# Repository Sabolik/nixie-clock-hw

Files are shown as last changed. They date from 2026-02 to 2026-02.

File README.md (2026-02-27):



PCB render

# HW

- ESP32-C3 MCU
- DC/DC, non-isolated PWM power converter
- USB-C 5V power input

- up to 6 nixie tubes

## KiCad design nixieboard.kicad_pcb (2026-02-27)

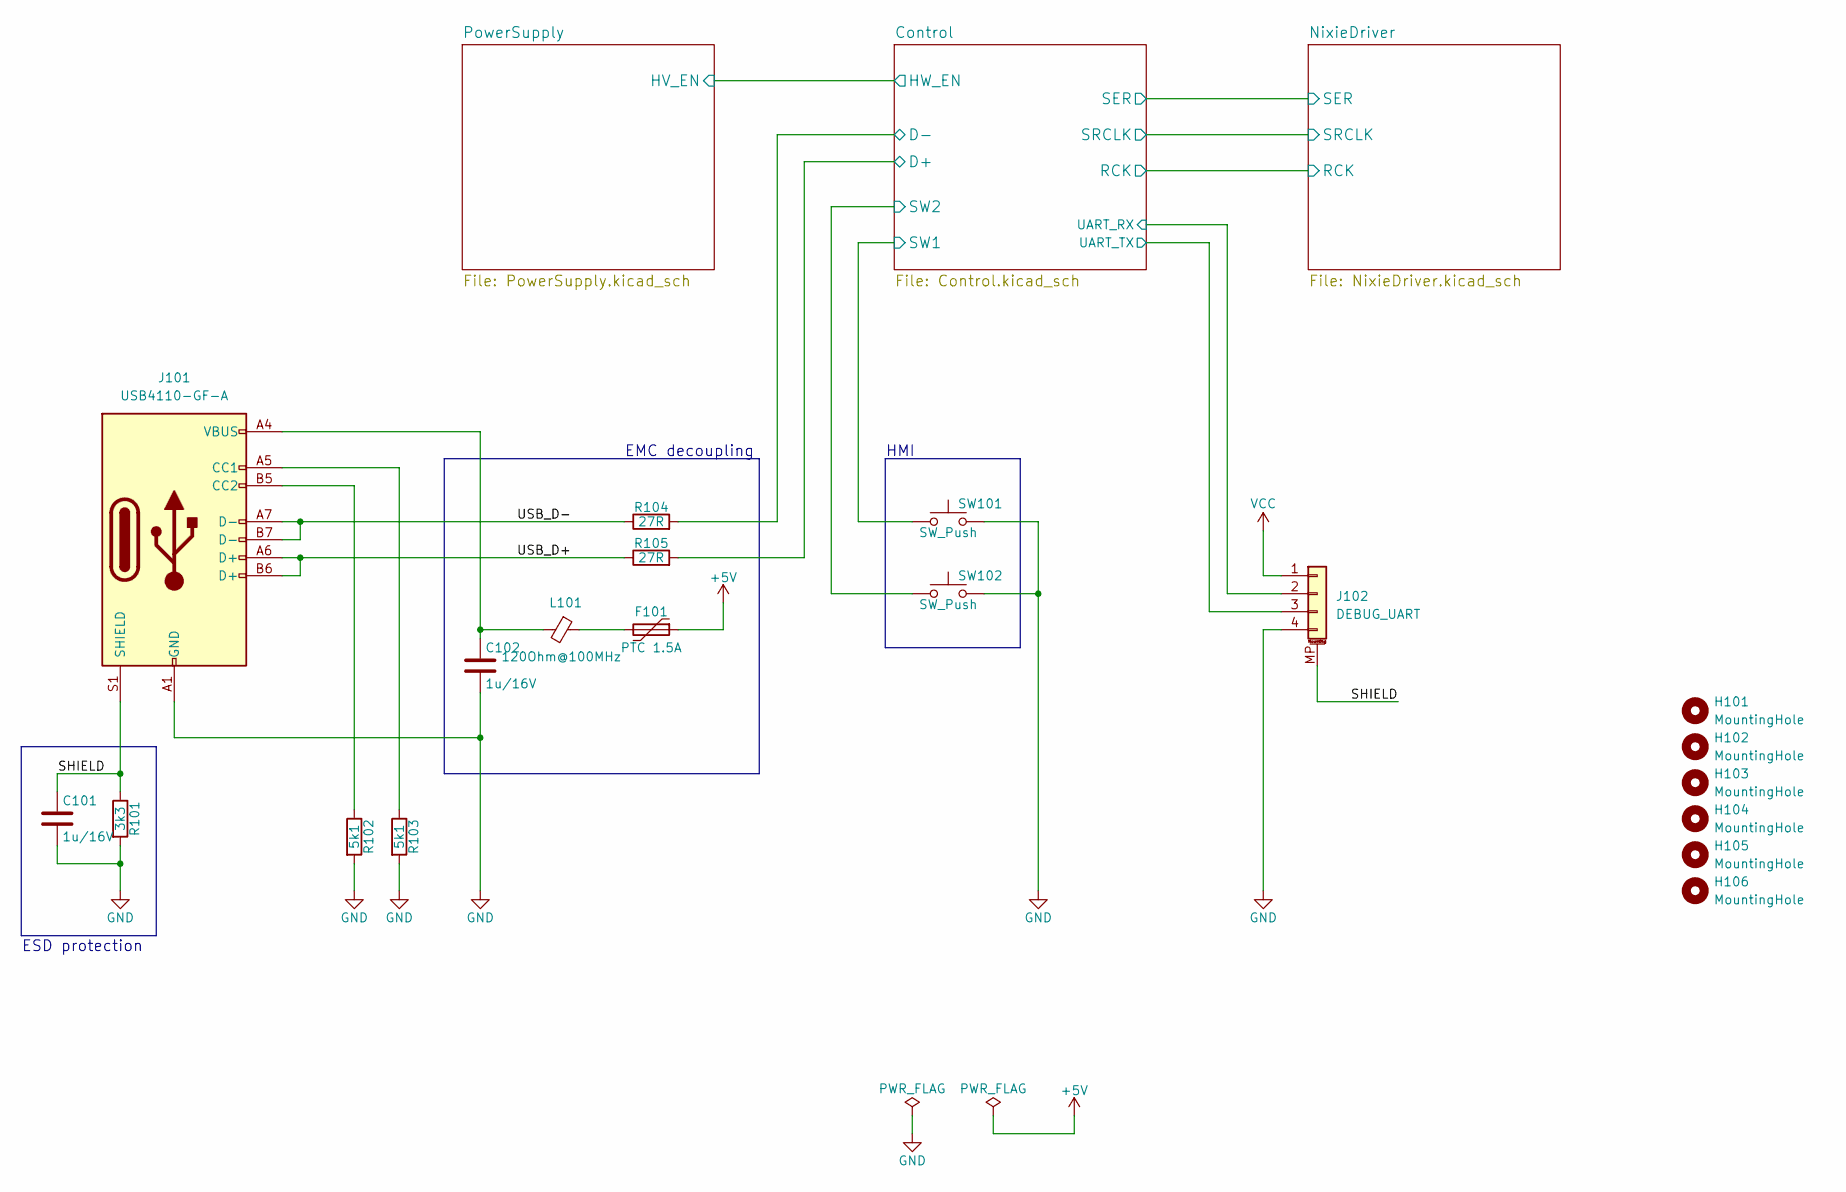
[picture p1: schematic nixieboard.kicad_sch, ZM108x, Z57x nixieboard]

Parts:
C101, C102: 1u/16V; C_0805_2012Metric
F101: PTC 1.5A; R_1812_4532Metric
H101, H102, H103, H104, H105, H106: MountingHole; MountingHole_3.2mm_M3
J101: USB4110-GF-A; USB_C_Receptacle_GCT_USB4110
J102: DEBUG_UART; Molex_PicoBlade_53261-0471_1x04-1MP_P1.25mm_Horizontal
L101: 120Ohm@100MHz; L_0805_2012Metric
R101: 3k3; R_0805_2012Metric
R102, R103: 5k1; R_0805_2012Metric
R104, R105: 27R; R_0805_2012Metric
SW101, SW102: SW_Push; SW_SPST_PTS645

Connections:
+5V: F101.1; also elsewhere on the board
/Control/D+: R105.2; also elsewhere on the board
/Control/D-: R104.2; also elsewhere on the board
/Control/SW1: SW101.1; also elsewhere on the board
/Control/SW2: SW102.1; also elsewhere on the board
/Control/UART_RX: J102.2; also elsewhere on the board
/Control/UART_TX: J102.3; also elsewhere on the board
/SHIELD: C101.1, J101.S1 (SHIELD), J102.MP (MountPin), R101.1
/USB_D+: J101.A6 (D+), J101.B6 (D+), R105.1
/USB_D-: J101.A7 (D-), J101.B7 (D-), R104.1
GND: C101.2, C102.2, J101.A1 (GND), J101.A12 (GND), J101.B1 (GND), J101.B12 (GND), J102.4, R101.2, R102.2, R103.2, SW101.2, SW102.2; also elsewhere on the board
unnamed: C102.1, J101.A4 (VBUS), J101.A9 (VBUS), J101.B4 (VBUS), J101.B9 (VBUS), L101.2
unnamed: F101.2, L101.1
unnamed: J101.A5 (CC1), R103.1
unnamed: J101.B5 (CC2), R102.1
VCC: J102.1; also elsewhere on the board

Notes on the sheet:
EMC decoupling
ESD protection
HMI

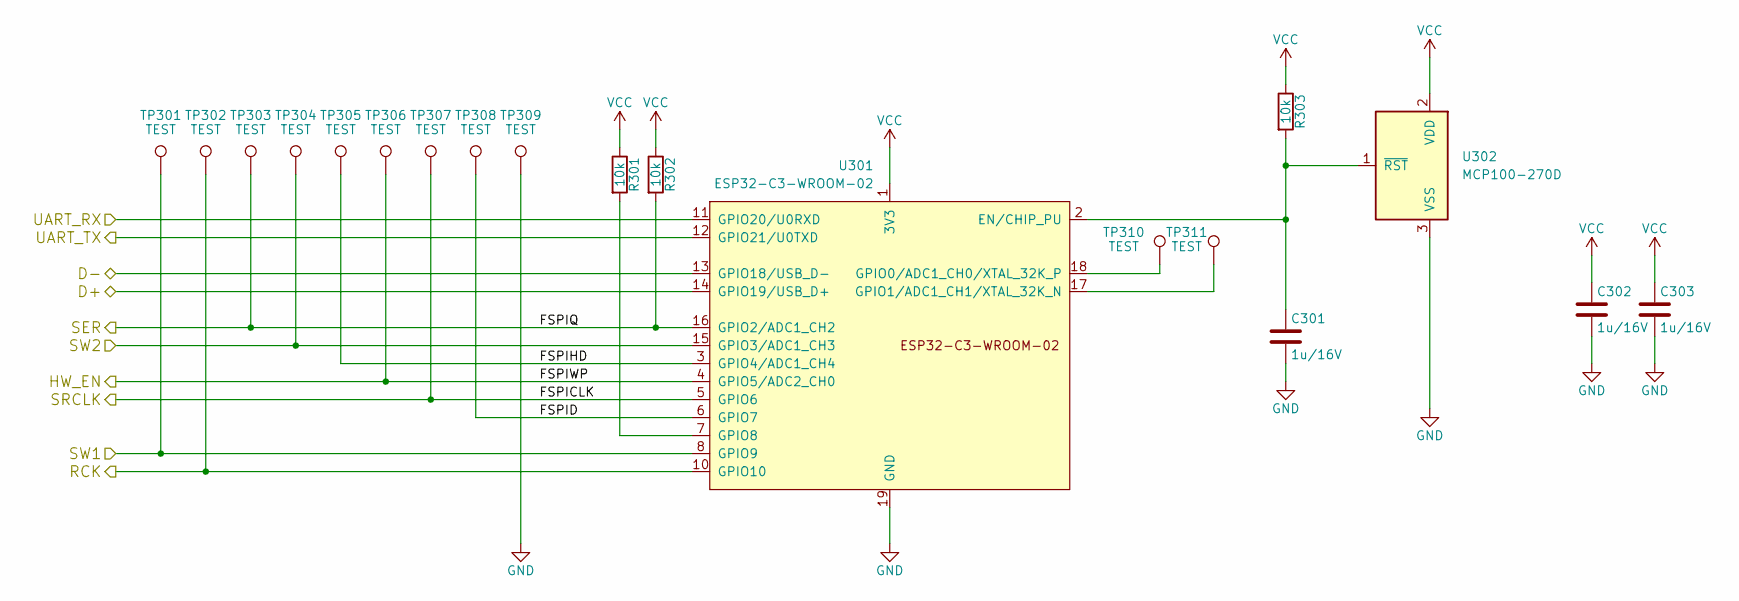
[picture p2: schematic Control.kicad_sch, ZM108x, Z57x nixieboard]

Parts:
C301, C302, C303: 1u/16V; C_0805_2012Metric
R301, R302, R303: 10k; R_0805_2012Metric
TP301, TP302, TP303, TP304, TP305, TP306, TP307, TP308, TP309, TP310, TP311: TEST; TestPoint_Pad_D1.5mm
U301: ESP32-C3-WROOM-02
U302: MCP100-270D; SOT-23-3

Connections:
/Control/D+: U301.14 (GPIO19/USB_D+); also elsewhere on the board
/Control/D-: U301.13 (GPIO18/USB_D-); also elsewhere on the board
/Control/FSPICLK: TP307.1, U301.5 (GPIO6); also elsewhere on the board
/Control/FSPID: TP308.1, U301.6 (GPIO7)
/Control/FSPIHD: TP305.1, U301.3 (GPIO4/ADC1_CH4)
/Control/FSPIQ: R302.2, TP303.1, U301.16 (GPIO2/ADC1_CH2); also elsewhere on the board
/Control/FSPIWP: TP306.1, U301.4 (GPIO5/ADC2_CH0); also elsewhere on the board
/Control/RCK: TP302.1, U301.10 (GPIO10); also elsewhere on the board
/Control/SW1: TP301.1, U301.8 (GPIO9); also elsewhere on the board
/Control/SW2: TP304.1, U301.15 (GPIO3/ADC1_CH3); also elsewhere on the board
/Control/UART_RX: U301.11 (GPIO20/U0RXD); also elsewhere on the board
/Control/UART_TX: U301.12 (GPIO21/U0TXD); also elsewhere on the board
GND: C301.2, C302.2, C303.2, TP309.1, U301.9 (GND), U301.19 (GND), U302.3 (VSS); also elsewhere on the board
unnamed: C301.1, R303.2, U301.2 (EN/CHIP_PU), U302.1 (~RST)
unnamed: TP310.1, U301.18 (GPIO0/ADC1_CH0/XTAL_32K_P)
unnamed: TP311.1, U301.17 (GPIO1/ADC1_CH1/XTAL_32K_N)
unnamed: R301.2, U301.7 (GPIO8)
VCC: C302.1, C303.1, R301.1, R302.1, R303.1, U301.1 (3V3), U302.2 (VDD); also elsewhere on the board

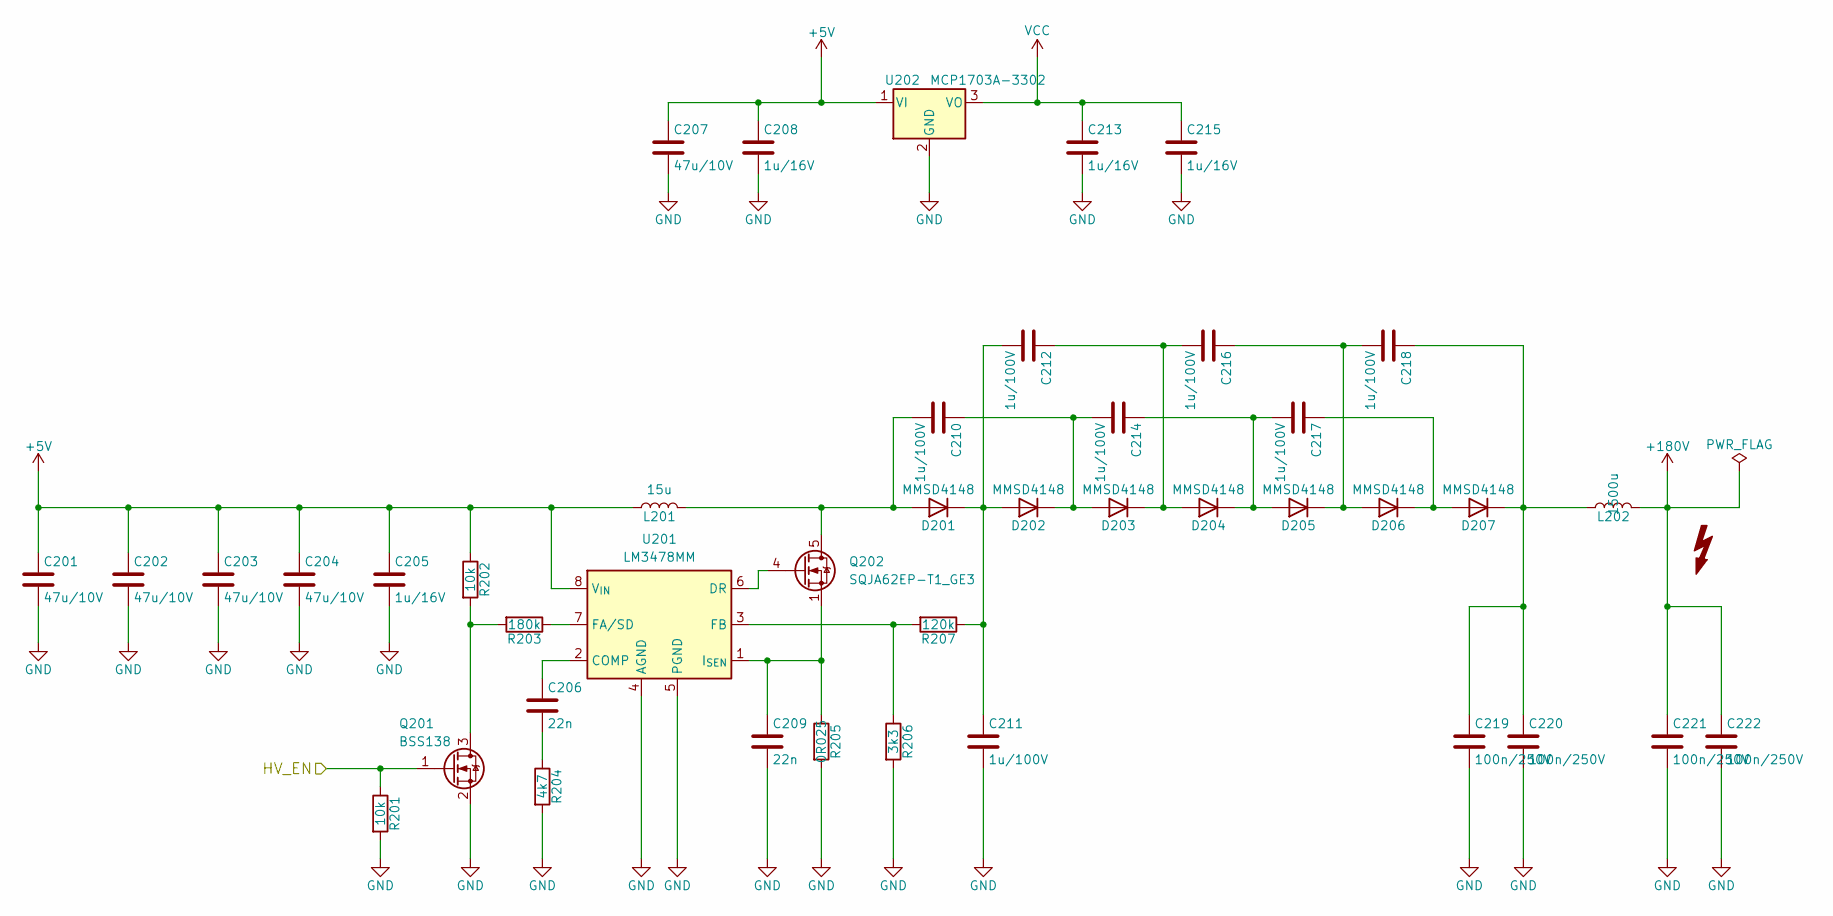
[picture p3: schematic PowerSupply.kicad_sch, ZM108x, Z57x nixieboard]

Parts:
C201, C202, C203, C204, C207: 47u/10V; C_1206_3216Metric
C205, C208, C213, C215: 1u/16V; C_0805_2012Metric
C206, C209: 22n; C_0805_2012Metric
C210, C211, C212, C214, C216, C217, C218: 1u/100V; C_1206_3216Metric
C219, C220, C221, C222: 100n/250V; C_1206_3216Metric
D201, D202, D203, D204, D205, D206, D207: MMSD4148; D_SOD-123
L201: 15u; L_Bourns_SRR1208_12.7x12.7mm
L202: 1500u; L_1812_4532Metric
Q201: BSS138; SOT-23
Q202: SQJA62EP-T1_GE3; PowerPAK_SO-8_Single
R201, R202: 10k; R_0805_2012Metric
R203: 180k; R_0805_2012Metric
R204: 4k7; R_0805_2012Metric
R205: 0R025; R_0805_2012Metric
R206: 3k3; R_0805_2012Metric
R207: 120k; R_0805_2012Metric
U201: LM3478MM; VSSOP-8_3.0x3.0mm_P0.65mm
U202: MCP1703A-3302; SOT-223-3_TabPin2

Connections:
+5V: C201.1, C202.1, C203.1, C204.1, C205.1, C207.1, C208.1, L201.1, R202.1, U201.8 (V_{IN}), U202.1 (VI); also elsewhere on the board
/Control/FSPIWP: Q201.1 (G), R201.1; also elsewhere on the board
GND: C201.2, C202.2, C203.2, C204.2, C205.2, C207.2, C208.2, C209.2, C211.2, C213.2, C215.2, C219.2, C220.2, C221.2, C222.2, Q201.2 (S), R201.2, R204.2, R205.2, R206.2, U201.4 (AGND), U201.5 (PGND), U202.2 (GND); also elsewhere on the board
unnamed: C206.2, R204.1
unnamed: C210.2, D201.2 (A), L201.2, Q202.5 (D)
unnamed: C211.1, C212.2, D201.1 (K), D202.2 (A), R207.1
unnamed: C210.1, C214.2, D202.1 (K), D203.2 (A)
unnamed: C212.1, C216.2, D203.1 (K), D204.2 (A)
unnamed: C214.1, C217.2, D204.1 (K), D205.2 (A)
unnamed: C216.1, C218.2, D205.1 (K), D206.2 (A)
unnamed: C217.1, D206.1 (K), D207.2 (A)
unnamed: C218.1, C219.1, C220.1, D207.1 (K), L202.1
unnamed: Q201.3 (D), R202.2, R203.2
unnamed: Q202.4 (G), U201.6 (DR)
unnamed: C206.1, U201.2 (COMP)
unnamed: R203.1, U201.7 (FA/SD)
unnamed: R206.1, R207.2, U201.3 (FB)
unnamed: C209.1, Q202.1 (S), Q202.2 (S), Q202.3 (S), R205.1, U201.1 (I_{SEN})
VCC: C213.1, C215.1, U202.3 (VO); also elsewhere on the board
Vdrive: C221.1, C222.1, L202.2; also elsewhere on the board

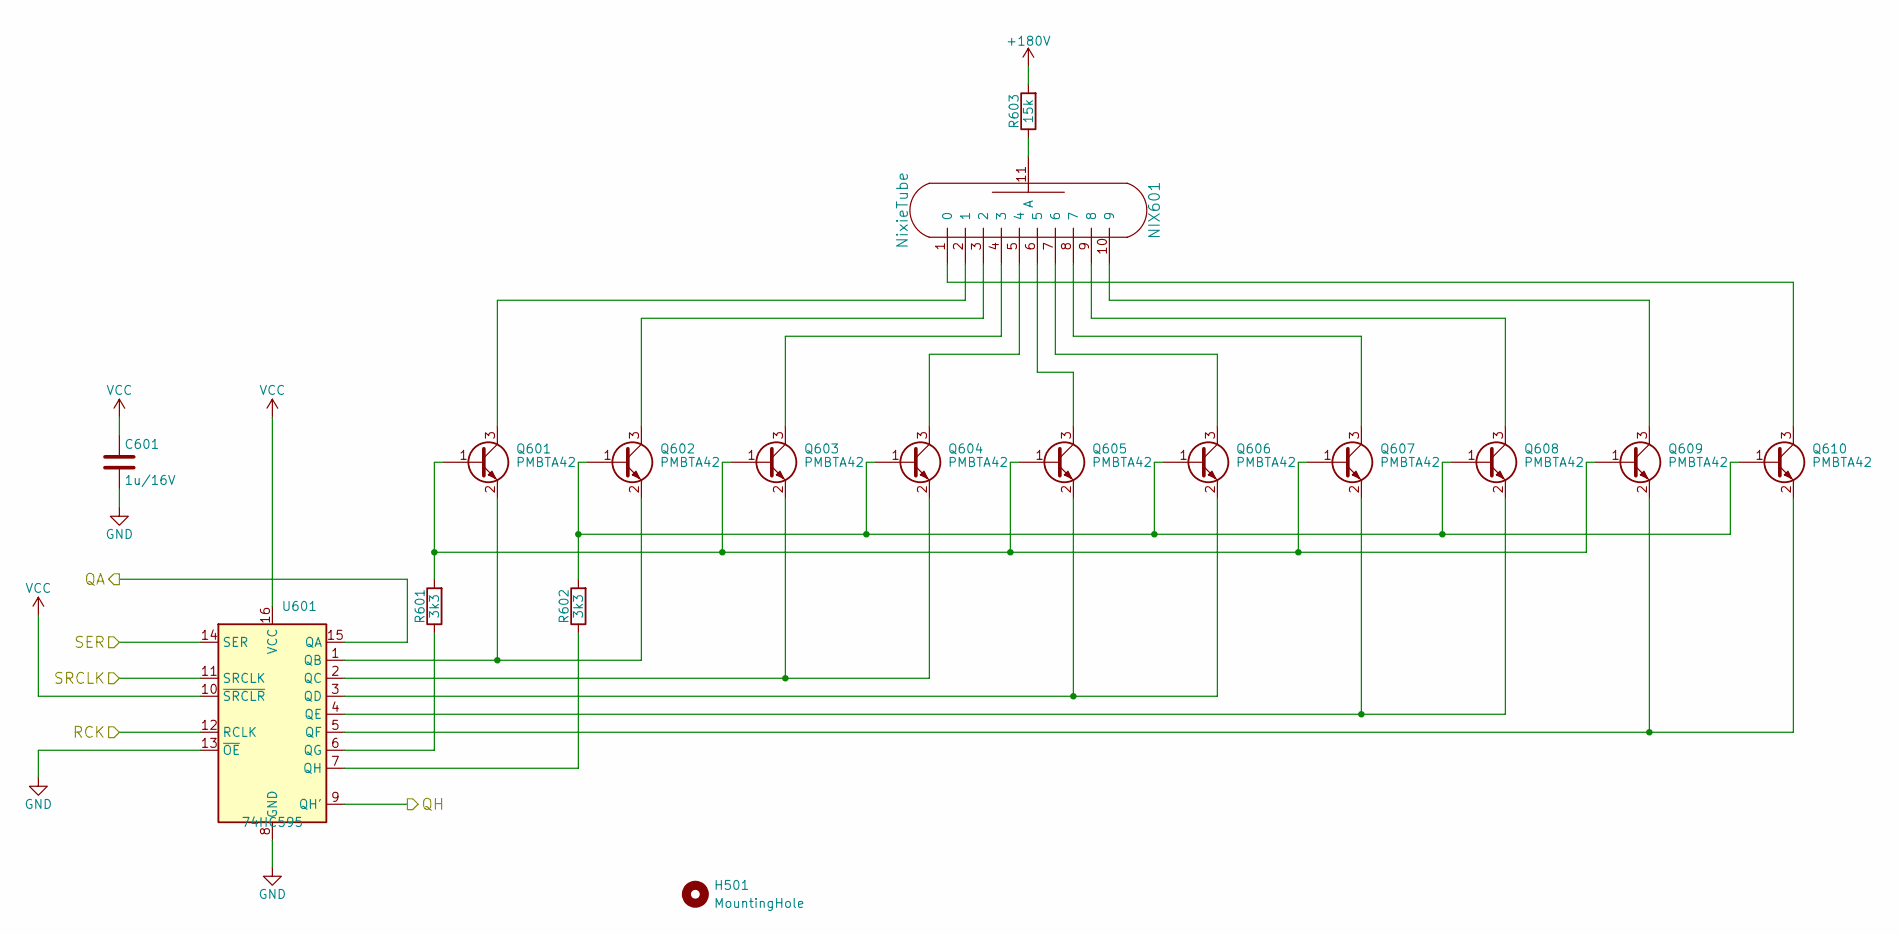
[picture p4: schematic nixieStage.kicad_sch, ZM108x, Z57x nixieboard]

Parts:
C601: 1u/16V; C_0805_2012Metric
H501: MountingHole; MountingHole_5.3mm_M5
NIX601: NixieTube; Zxxx
Q601, Q602, Q603, Q604, Q605, Q606, Q607, Q608, Q609, Q610: PMBTA42; SOT-23
R601, R602: 3k3; R_0603_1608Metric
R603: 15k; R_1206_3216Metric
U601: 74HC595; TSSOP-16_4.4x5mm_P0.65mm

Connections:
/Control/FSPICLK: U601.11 (SRCLK); also elsewhere on the board
/Control/RCK: U601.12 (RCLK); also elsewhere on the board
/NixieDriver/neon0/NEON: U601.15 (QA); also elsewhere on the board
/NixieDriver/nixieStage0/QH: U601.14 (SER); also elsewhere on the board
/NixieDriver/nixieStage1/QH: U601.9 (QH'); also elsewhere on the board
GND: C601.2, U601.8 (GND), U601.13 (~OE); also elsewhere on the board
unnamed: NIX601.1 (0), Q610.3 (C)
unnamed: NIX601.2 (1), Q601.3 (C)
unnamed: NIX601.3 (2), Q602.3 (C)
unnamed: NIX601.4 (3), Q603.3 (C)
unnamed: NIX601.5 (4), Q604.3 (C)
unnamed: NIX601.6 (5), Q605.3 (C)
unnamed: NIX601.7 (6), Q606.3 (C)
unnamed: NIX601.8 (7), Q607.3 (C)
unnamed: NIX601.9 (8), Q608.3 (C)
unnamed: NIX601.10 (9), Q609.3 (C)
unnamed: NIX601.11 (A), R603.1
unnamed: Q601.1 (B), Q603.1 (B), Q605.1 (B), Q607.1 (B), Q609.1 (B), R601.2
unnamed: Q601.2 (E), Q602.2 (E), U601.1 (QB)
unnamed: Q602.1 (B), Q604.1 (B), Q606.1 (B), Q608.1 (B), Q610.1 (B), R602.2
unnamed: Q603.2 (E), Q604.2 (E), U601.2 (QC)
unnamed: Q605.2 (E), Q606.2 (E), U601.3 (QD)
unnamed: Q607.2 (E), Q608.2 (E), U601.4 (QE)
unnamed: Q609.2 (E), Q610.2 (E), U601.5 (QF)
unnamed: R601.1, U601.6 (QG)
unnamed: R602.1, U601.7 (QH)
VCC: C601.1, U601.10 (~SRCLR), U601.16 (VCC); also elsewhere on the board
Vdrive: R603.2; also elsewhere on the board

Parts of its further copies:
C501, C701, C901, C1001, C1201: 1u/16V; C_0805_2012Metric
H601, H701, H901, H1001, H1201: MountingHole; MountingHole_5.3mm_M5
NIX501, NIX701, NIX901, NIX1001, NIX1201: NixieTube; Zxxx
Q501, Q502, Q503, Q504, Q505, Q506, Q507, Q508, Q509, Q510, Q701, Q702, Q703, Q704, Q705, Q706, Q707, Q708, Q709, Q710, Q901, Q902, Q903, Q904, Q905, Q906, Q907, Q908, Q909, Q910, Q1001, Q1002, Q1003, Q1004, Q1005, Q1006, Q1007, Q1008, Q1009, Q1010, Q1201, Q1202, Q1203, Q1204, Q1205, Q1206, Q1207, Q1208, Q1209, Q1210: PMBTA42; SOT-23
R501, R502, R701, R702, R901, R902, R1001, R1002, R1201, R1202: 3k3; R_0603_1608Metric
R503, R703, R903, R1003, R1203: 15k; R_1206_3216Metric
U501, U701, U901, U1001, U1201: 74HC595; TSSOP-16_4.4x5mm_P0.65mm

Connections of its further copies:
/Control/FSPICLK: U501.11 (SRCLK), U701.11 (SRCLK), U901.11 (SRCLK), U1001.11 (SRCLK), U1201.11 (SRCLK); also elsewhere on the board
/Control/FSPIQ: U501.14 (SER); also elsewhere on the board
/Control/RCK: U501.12 (RCLK), U701.12 (RCLK), U901.12 (RCLK), U1001.12 (RCLK), U1201.12 (RCLK); also elsewhere on the board
/NixieDriver/neon1/NEON: U901.15 (QA); also elsewhere on the board
/NixieDriver/nixieStage0/QA: U501.15 (QA)
/NixieDriver/nixieStage0/QH: U501.9 (QH'); also elsewhere on the board
/NixieDriver/nixieStage1/QH: U701.14 (SER); also elsewhere on the board
/NixieDriver/nixieStage2/QA: U701.15 (QA)
/NixieDriver/nixieStage2/QH: U701.9 (QH'), U901.14 (SER)
/NixieDriver/nixieStage3/QH: U901.9 (QH'), U1001.14 (SER)
/NixieDriver/nixieStage4/QA: U1001.15 (QA)
/NixieDriver/nixieStage4/QH: U1001.9 (QH'), U1201.14 (SER)
/NixieDriver/nixieStage5/QA: U1201.15 (QA)
/NixieDriver/nixieStage5/QH: U1201.9 (QH')
GND: C501.2, C701.2, C901.2, C1001.2, C1201.2, U501.8 (GND), U501.13 (~OE), U701.8 (GND), U701.13 (~OE), U901.8 (GND), U901.13 (~OE), U1001.8 (GND), U1001.13 (~OE), U1201.8 (GND), U1201.13 (~OE); also elsewhere on the board
unnamed: NIX501.1 (0), Q510.3 (C)
unnamed: NIX501.2 (1), Q501.3 (C)
unnamed: NIX501.3 (2), Q502.3 (C)
unnamed: NIX501.4 (3), Q503.3 (C)
unnamed: NIX501.5 (4), Q504.3 (C)
unnamed: NIX501.6 (5), Q505.3 (C)
unnamed: NIX501.7 (6), Q506.3 (C)
unnamed: NIX501.8 (7), Q507.3 (C)
unnamed: NIX501.9 (8), Q508.3 (C)
unnamed: NIX501.10 (9), Q509.3 (C)
unnamed: NIX501.11 (A), R503.1
unnamed: NIX701.1 (0), Q710.3 (C)
unnamed: NIX701.2 (1), Q701.3 (C)
unnamed: NIX701.3 (2), Q702.3 (C)
unnamed: NIX701.4 (3), Q703.3 (C)
unnamed: NIX701.5 (4), Q704.3 (C)
unnamed: NIX701.6 (5), Q705.3 (C)
unnamed: NIX701.7 (6), Q706.3 (C)
unnamed: NIX701.8 (7), Q707.3 (C)
unnamed: NIX701.9 (8), Q708.3 (C)
unnamed: NIX701.10 (9), Q709.3 (C)
unnamed: NIX701.11 (A), R703.1
unnamed: NIX901.1 (0), Q910.3 (C)
unnamed: NIX901.2 (1), Q901.3 (C)
unnamed: NIX901.3 (2), Q902.3 (C)
unnamed: NIX901.4 (3), Q903.3 (C)
unnamed: NIX901.5 (4), Q904.3 (C)
unnamed: NIX901.6 (5), Q905.3 (C)
unnamed: NIX901.7 (6), Q906.3 (C)
unnamed: NIX901.8 (7), Q907.3 (C)
unnamed: NIX901.9 (8), Q908.3 (C)
unnamed: NIX901.10 (9), Q909.3 (C)
unnamed: NIX901.11 (A), R903.1
unnamed: NIX1001.1 (0), Q1010.3 (C)
unnamed: NIX1001.2 (1), Q1001.3 (C)
unnamed: NIX1001.3 (2), Q1002.3 (C)
unnamed: NIX1001.4 (3), Q1003.3 (C)
unnamed: NIX1001.5 (4), Q1004.3 (C)
unnamed: NIX1001.6 (5), Q1005.3 (C)
unnamed: NIX1001.7 (6), Q1006.3 (C)
unnamed: NIX1001.8 (7), Q1007.3 (C)
unnamed: NIX1001.9 (8), Q1008.3 (C)
unnamed: NIX1001.10 (9), Q1009.3 (C)
unnamed: NIX1001.11 (A), R1003.1
unnamed: NIX1201.1 (0), Q1210.3 (C)
unnamed: NIX1201.2 (1), Q1201.3 (C)
unnamed: NIX1201.3 (2), Q1202.3 (C)
unnamed: NIX1201.4 (3), Q1203.3 (C)
unnamed: NIX1201.5 (4), Q1204.3 (C)
unnamed: NIX1201.6 (5), Q1205.3 (C)
unnamed: NIX1201.7 (6), Q1206.3 (C)
unnamed: NIX1201.8 (7), Q1207.3 (C)
unnamed: NIX1201.9 (8), Q1208.3 (C)
unnamed: NIX1201.10 (9), Q1209.3 (C)
unnamed: NIX1201.11 (A), R1203.1
unnamed: Q501.1 (B), Q503.1 (B), Q505.1 (B), Q507.1 (B), Q509.1 (B), R501.2
unnamed: Q501.2 (E), Q502.2 (E), U501.1 (QB)
unnamed: Q502.1 (B), Q504.1 (B), Q506.1 (B), Q508.1 (B), Q510.1 (B), R502.2
unnamed: Q503.2 (E), Q504.2 (E), U501.2 (QC)
unnamed: Q505.2 (E), Q506.2 (E), U501.3 (QD)
unnamed: Q507.2 (E), Q508.2 (E), U501.4 (QE)
unnamed: Q509.2 (E), Q510.2 (E), U501.5 (QF)
unnamed: Q701.1 (B), Q703.1 (B), Q705.1 (B), Q707.1 (B), Q709.1 (B), R701.2
unnamed: Q701.2 (E), Q702.2 (E), U701.1 (QB)
unnamed: Q702.1 (B), Q704.1 (B), Q706.1 (B), Q708.1 (B), Q710.1 (B), R702.2
unnamed: Q703.2 (E), Q704.2 (E), U701.2 (QC)
unnamed: Q705.2 (E), Q706.2 (E), U701.3 (QD)
unnamed: Q707.2 (E), Q708.2 (E), U701.4 (QE)
unnamed: Q709.2 (E), Q710.2 (E), U701.5 (QF)
unnamed: Q901.1 (B), Q903.1 (B), Q905.1 (B), Q907.1 (B), Q909.1 (B), R901.2
unnamed: Q901.2 (E), Q902.2 (E), U901.1 (QB)
unnamed: Q902.1 (B), Q904.1 (B), Q906.1 (B), Q908.1 (B), Q910.1 (B), R902.2
unnamed: Q903.2 (E), Q904.2 (E), U901.2 (QC)
unnamed: Q905.2 (E), Q906.2 (E), U901.3 (QD)
unnamed: Q907.2 (E), Q908.2 (E), U901.4 (QE)
unnamed: Q909.2 (E), Q910.2 (E), U901.5 (QF)
unnamed: Q1001.1 (B), Q1003.1 (B), Q1005.1 (B), Q1007.1 (B), Q1009.1 (B), R1001.2
unnamed: Q1001.2 (E), Q1002.2 (E), U1001.1 (QB)
unnamed: Q1002.1 (B), Q1004.1 (B), Q1006.1 (B), Q1008.1 (B), Q1010.1 (B), R1002.2
unnamed: Q1003.2 (E), Q1004.2 (E), U1001.2 (QC)
unnamed: Q1005.2 (E), Q1006.2 (E), U1001.3 (QD)
unnamed: Q1007.2 (E), Q1008.2 (E), U1001.4 (QE)
unnamed: Q1009.2 (E), Q1010.2 (E), U1001.5 (QF)
unnamed: Q1201.1 (B), Q1203.1 (B), Q1205.1 (B), Q1207.1 (B), Q1209.1 (B), R1201.2
unnamed: Q1201.2 (E), Q1202.2 (E), U1201.1 (QB)
unnamed: Q1202.1 (B), Q1204.1 (B), Q1206.1 (B), Q1208.1 (B), Q1210.1 (B), R1202.2
unnamed: Q1203.2 (E), Q1204.2 (E), U1201.2 (QC)
unnamed: Q1205.2 (E), Q1206.2 (E), U1201.3 (QD)
unnamed: Q1207.2 (E), Q1208.2 (E), U1201.4 (QE)
unnamed: Q1209.2 (E), Q1210.2 (E), U1201.5 (QF)
unnamed: R501.1, U501.6 (QG)
unnamed: R502.1, U501.7 (QH)
unnamed: R701.1, U701.6 (QG)
unnamed: R702.1, U701.7 (QH)
unnamed: R901.1, U901.6 (QG)
unnamed: R902.1, U901.7 (QH)
unnamed: R1001.1, U1001.6 (QG)
unnamed: R1002.1, U1001.7 (QH)
unnamed: R1201.1, U1201.6 (QG)
unnamed: R1202.1, U1201.7 (QH)
VCC: C501.1, C701.1, C901.1, C1001.1, C1201.1, U501.10 (~SRCLR), U501.16 (VCC), U701.10 (~SRCLR), U701.16 (VCC), U901.10 (~SRCLR), U901.16 (VCC), U1001.10 (~SRCLR), U1001.16 (VCC), U1201.10 (~SRCLR), U1201.16 (VCC); also elsewhere on the board
Vdrive: R503.2, R703.2, R903.2, R1003.2, R1203.2; also elsewhere on the board

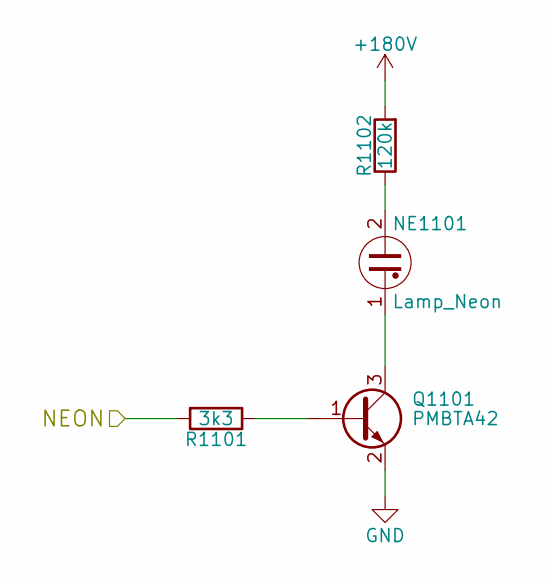
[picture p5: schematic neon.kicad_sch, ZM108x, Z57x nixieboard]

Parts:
NE1101: Lamp_Neon; Neon
Q1101: PMBTA42; SOT-23
R1101: 3k3; R_0603_1608Metric
R1102: 120k; R_1206_3216Metric

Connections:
/NixieDriver/neon1/NEON: R1101.2; also elsewhere on the board
GND: Q1101.2 (E); also elsewhere on the board
unnamed: NE1101.2, R1102.1
unnamed: Q1101.1 (B), R1101.1
unnamed: NE1101.1, Q1101.3 (C)
Vdrive: R1102.2; also elsewhere on the board

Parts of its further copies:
NE801: Lamp_Neon; Neon
Q801: PMBTA42; SOT-23
R801: 3k3; R_0603_1608Metric
R802: 120k; R_1206_3216Metric

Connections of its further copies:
/NixieDriver/neon0/NEON: R801.2; also elsewhere on the board
GND: Q801.2 (E); also elsewhere on the board
unnamed: NE801.2, R802.1
unnamed: Q801.1 (B), R801.1
unnamed: NE801.1, Q801.3 (C)
Vdrive: R802.2; also elsewhere on the board

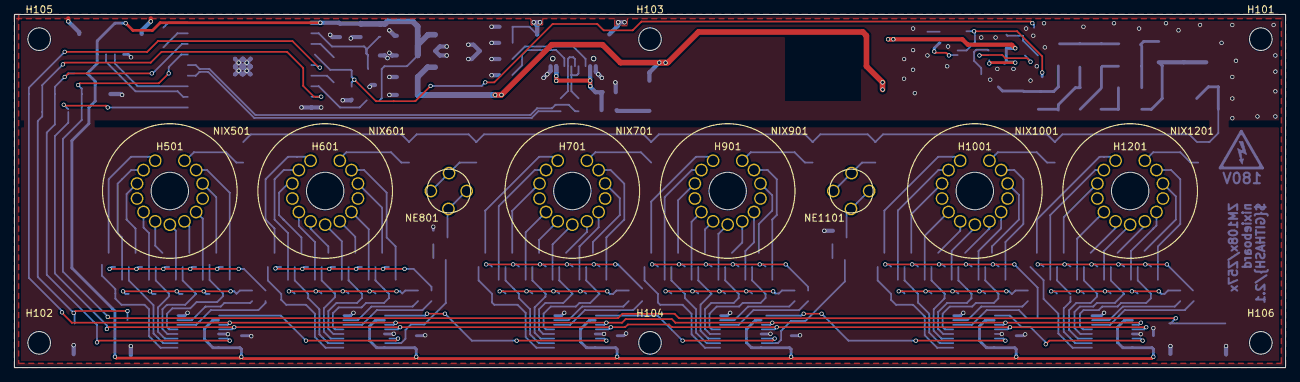
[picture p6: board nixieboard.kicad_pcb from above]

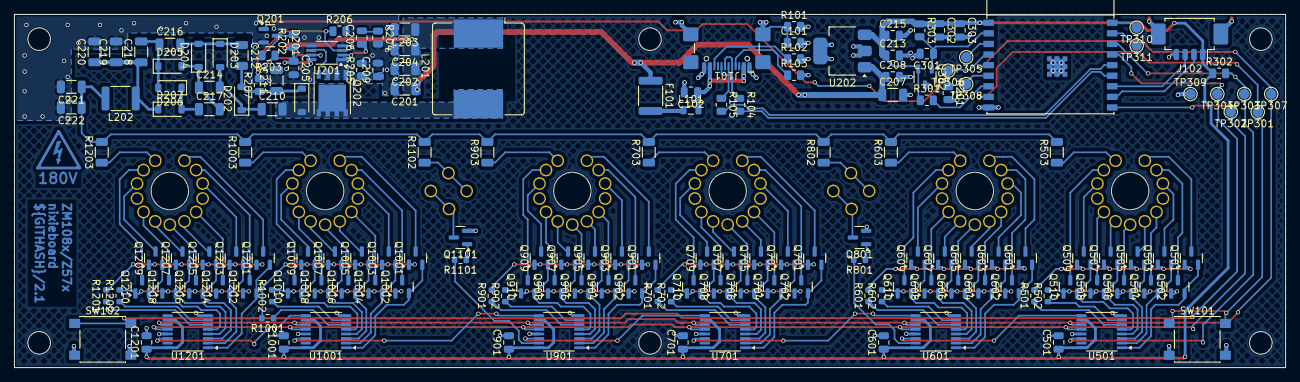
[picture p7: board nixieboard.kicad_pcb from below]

Board: 2 copper layers, 180.0 x 50.0 mm, 190 parts (170 on the bottom side), 175 nets.

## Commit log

2025-09-04 rev 2: new revision ready for manufacturing.
    Main updates:
    - switch to KiCad7
    - ESP8266 replaced with ESP32-C3
    - DCDC controler replaced
    - remove un-used capatitors
    [Control.kicad_sch, NixieDriver.kicad_sch, PowerSupply.kicad_sch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]
2025-09-04 add git hash
    [Control.kicad_sch, NixieDriver.kicad_sch, PowerSupply.kicad_sch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]
2025-09-05 CI: run ERC/DRC triggered by schematic/pcb update.
2025-09-05 pcb: add drc solder mask bridge violation to be ignored
2025-09-05 doc: add current release PCB render to readme
2025-09-06 schema: bom: PNs update
    [Control.kicad_sch, PowerSupply.kicad_sch, neon.kicad_sch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]
2026-02-27 BoM: optimize parts
    [Control.kicad_sch, PowerSupply.kicad_sch, neon.kicad_sch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]
2026-02-27 pcb: fix HV generator enable input
    [Control.kicad_sch, NixieDriver.kicad_sch, PowerSupply.kicad_sch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]
2026-02-27 Update README with latest PCB render and formatting
